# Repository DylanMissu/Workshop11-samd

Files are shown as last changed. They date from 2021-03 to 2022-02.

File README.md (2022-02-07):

# LoRaWAN Logger ZERO+
| Front | Back |
|---|---|
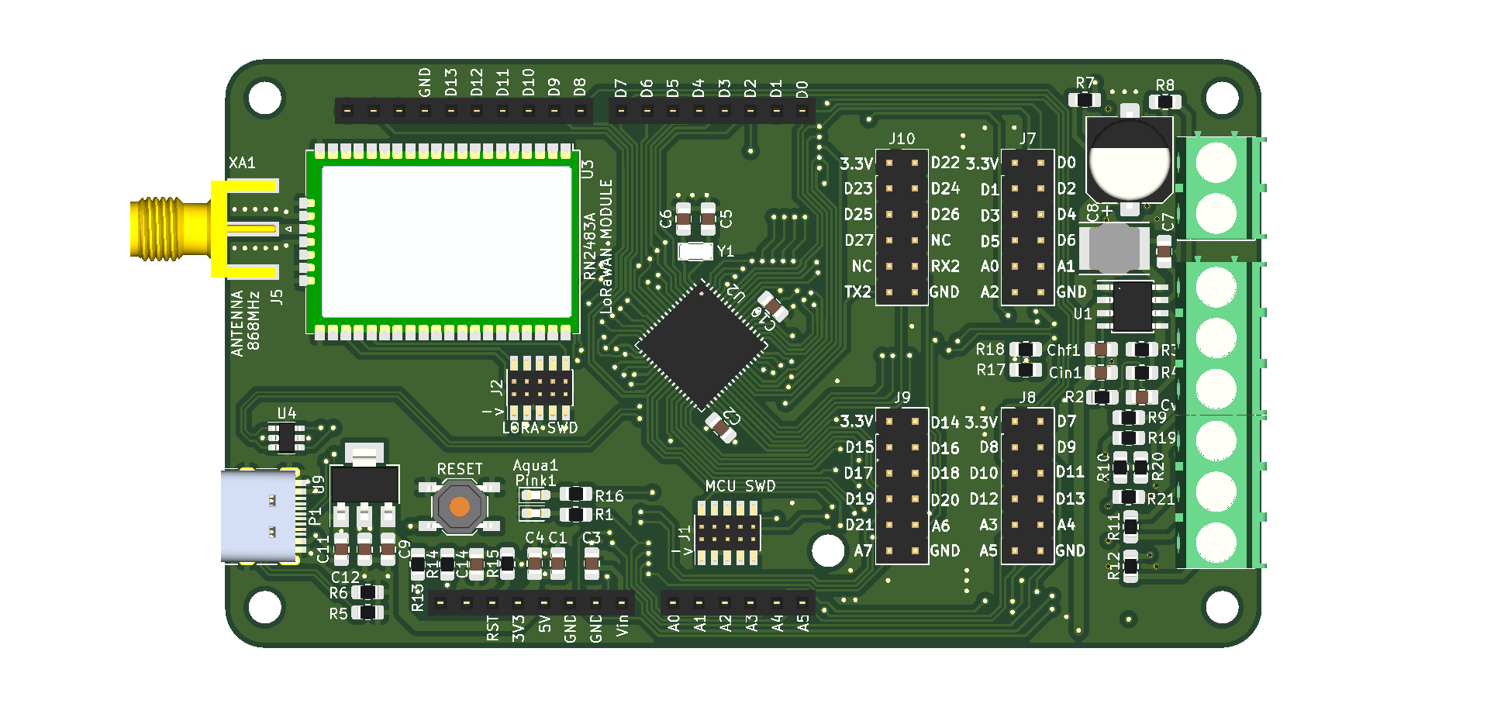
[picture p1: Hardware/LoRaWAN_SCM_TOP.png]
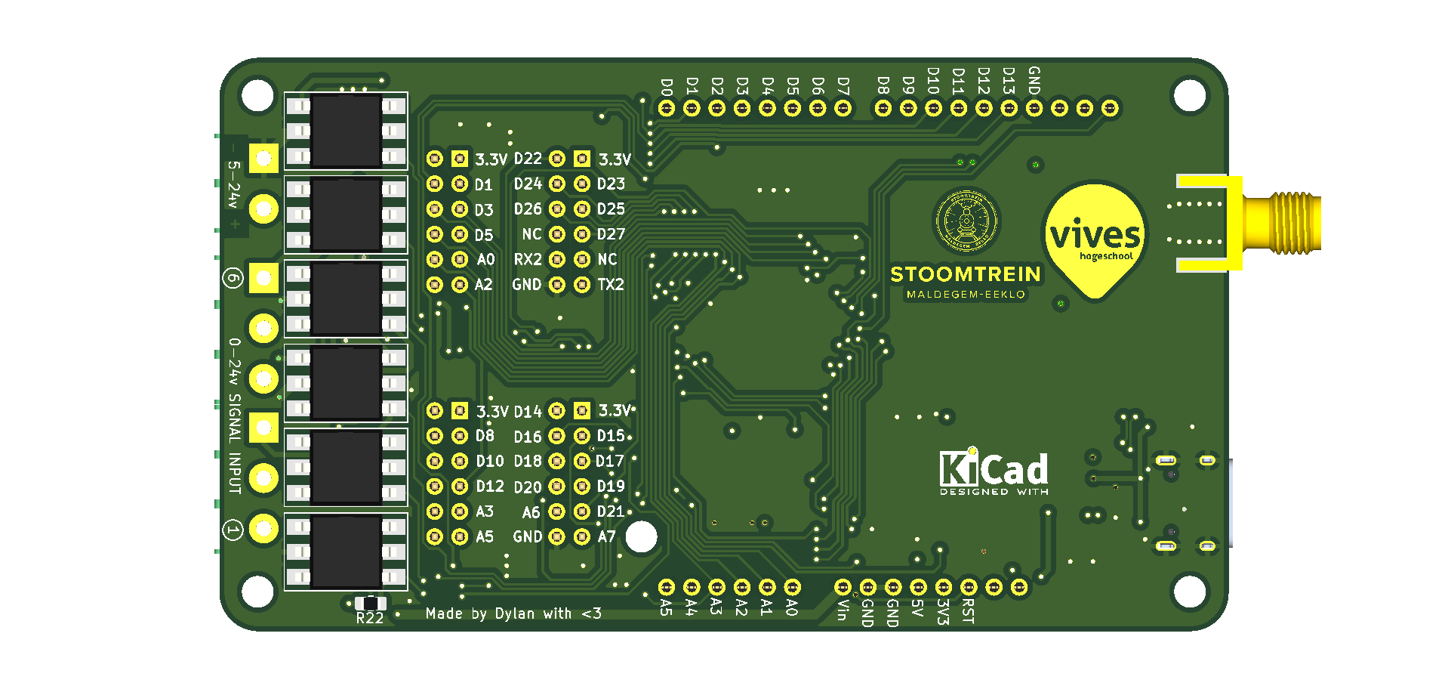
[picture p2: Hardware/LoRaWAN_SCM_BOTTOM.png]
| |  |

## Description
This board was made to help automate steam train management in an NPO. It is used to send status signals to a central server through LoRaWAN so the workers don’t have to go on site and check the states. There will also be an expansion board with relays to switch certain peripherals remotely.
It is equipped with 6 individual 24v tolerant isolated digital inputs. It can also be powered by 24v DC because it uses a buck converter to step the voltage down to 3.3v
Here are some other specifications:
* Microcontroller: ATSAMD21J18
* Flash: 256KB
* SRAM: 64KB
* Frequency: 48MHz
* ADC: 20-Channel 12bit
* DAC: Single-Channel 10bit 
* Pins: 52 GPIO pins

## This repository contains
* installation guide
* usage guide
* PCB and schematic files
* bootloader code and binaries
* ArduinoCore-samd libraries

## Installation
First open the configuration editor in Arduino under "File -> Preferences"
Then next to "Additional Boards Manager URLs" add the following url:
```
https://raw.githubusercontent.com/dylanmsu/Workshop11-samd/master/Workshop11Core-samd/package_workshop11_index.json
```

For a more detailed explanation, refer to [this guide](https://support.arduino.cc/hc/en-us/articles/360016119519-How-to-add-boards-in-the-board-manager).

## Usage
TODO

## Schematic
TODO

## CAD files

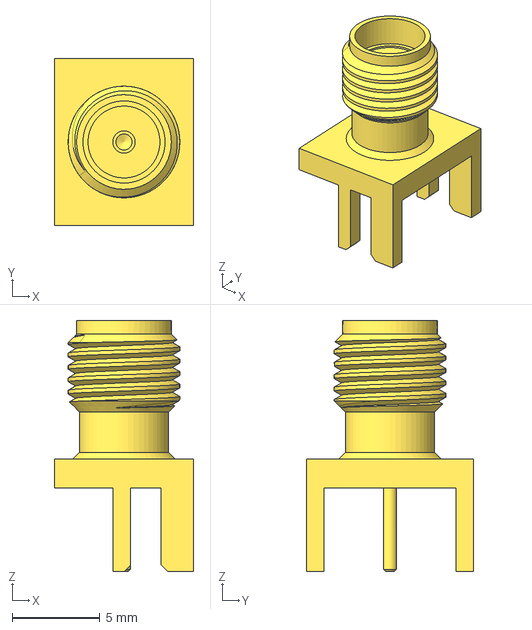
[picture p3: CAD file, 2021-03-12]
Hardware/3d models/142-0701-801--3DModel-STEP-231308.STEP
7.92 x 9.53 x 14.3 mm

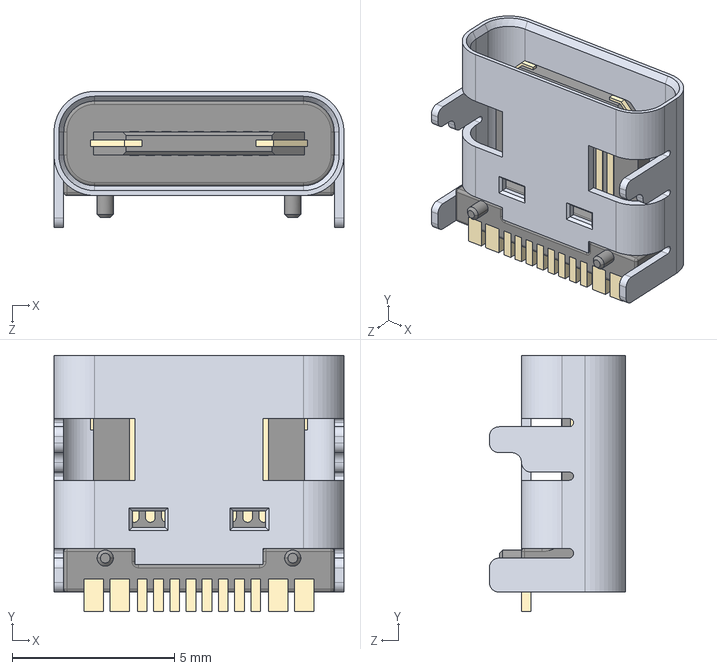
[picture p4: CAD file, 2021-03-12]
Hardware/3d models/USB Type C Port (SMD Type).STEP
8.94 x 7.90 x 4.20 mm

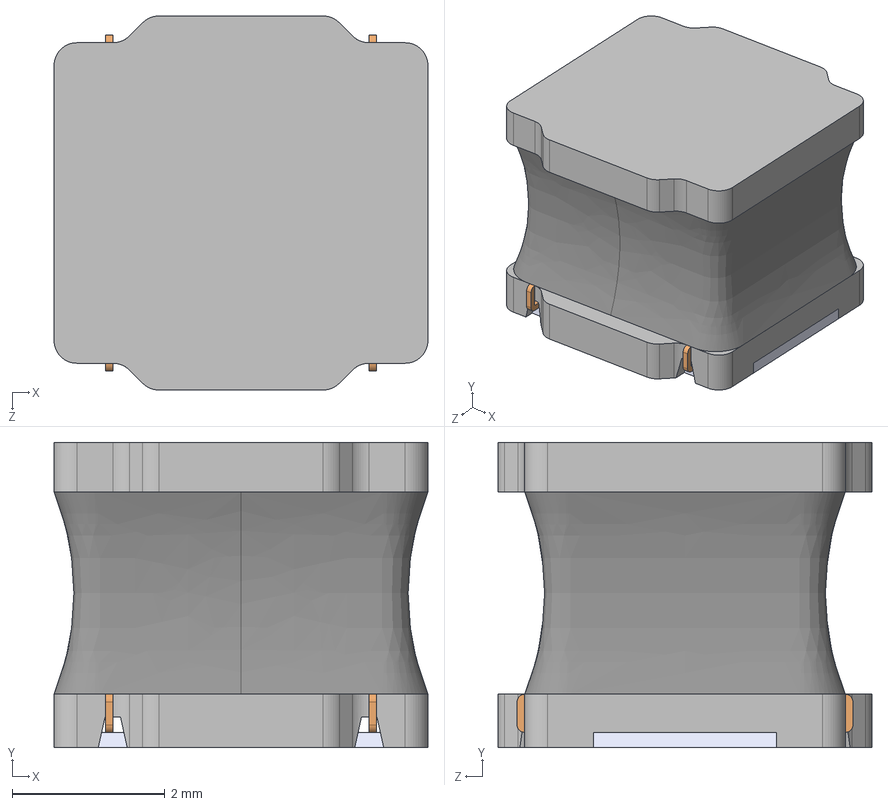
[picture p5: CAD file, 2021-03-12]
Hardware/3d models/LQH5BPN100M38K.STEP
4.90 x 4.00 x 4.90 mm

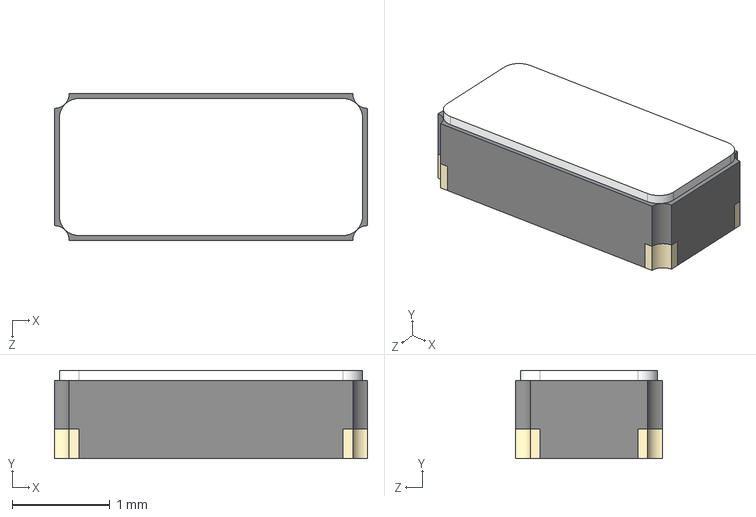
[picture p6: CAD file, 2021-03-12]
Hardware/3d models/ABS07-32.768KHZ-T--3DModel-STEP-56544.STEP
3.20 x 0.9 x 1.50 mm

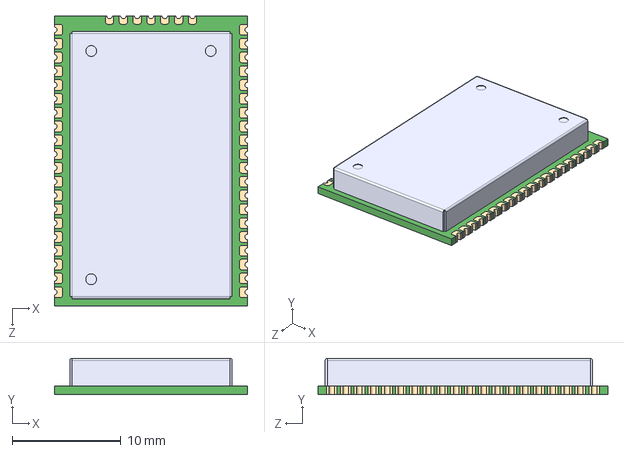
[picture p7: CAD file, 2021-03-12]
Hardware/3d models/RM095--3DModel-STEP-56544.STEP
17.8 x 3.34 x 26.7 mm

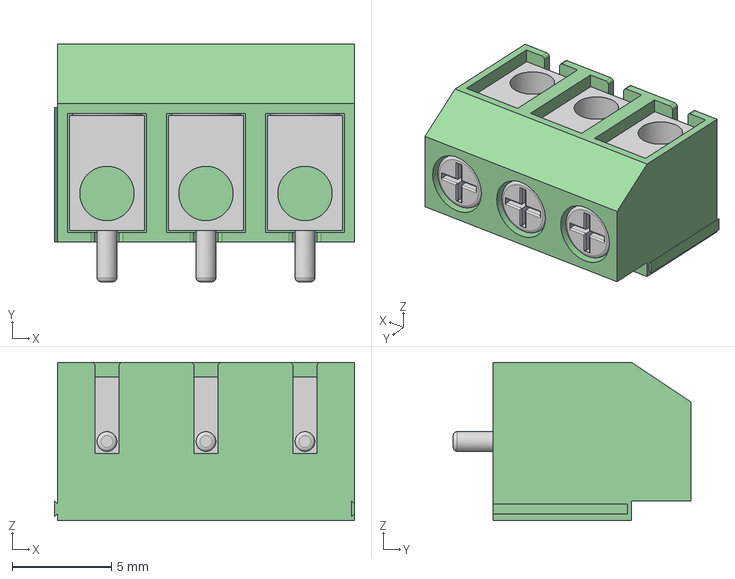
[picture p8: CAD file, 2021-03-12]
Hardware/3d models/Screw Terminal Block 5mm 3-way.step
15.2 x 12.0 x 8.00 mm

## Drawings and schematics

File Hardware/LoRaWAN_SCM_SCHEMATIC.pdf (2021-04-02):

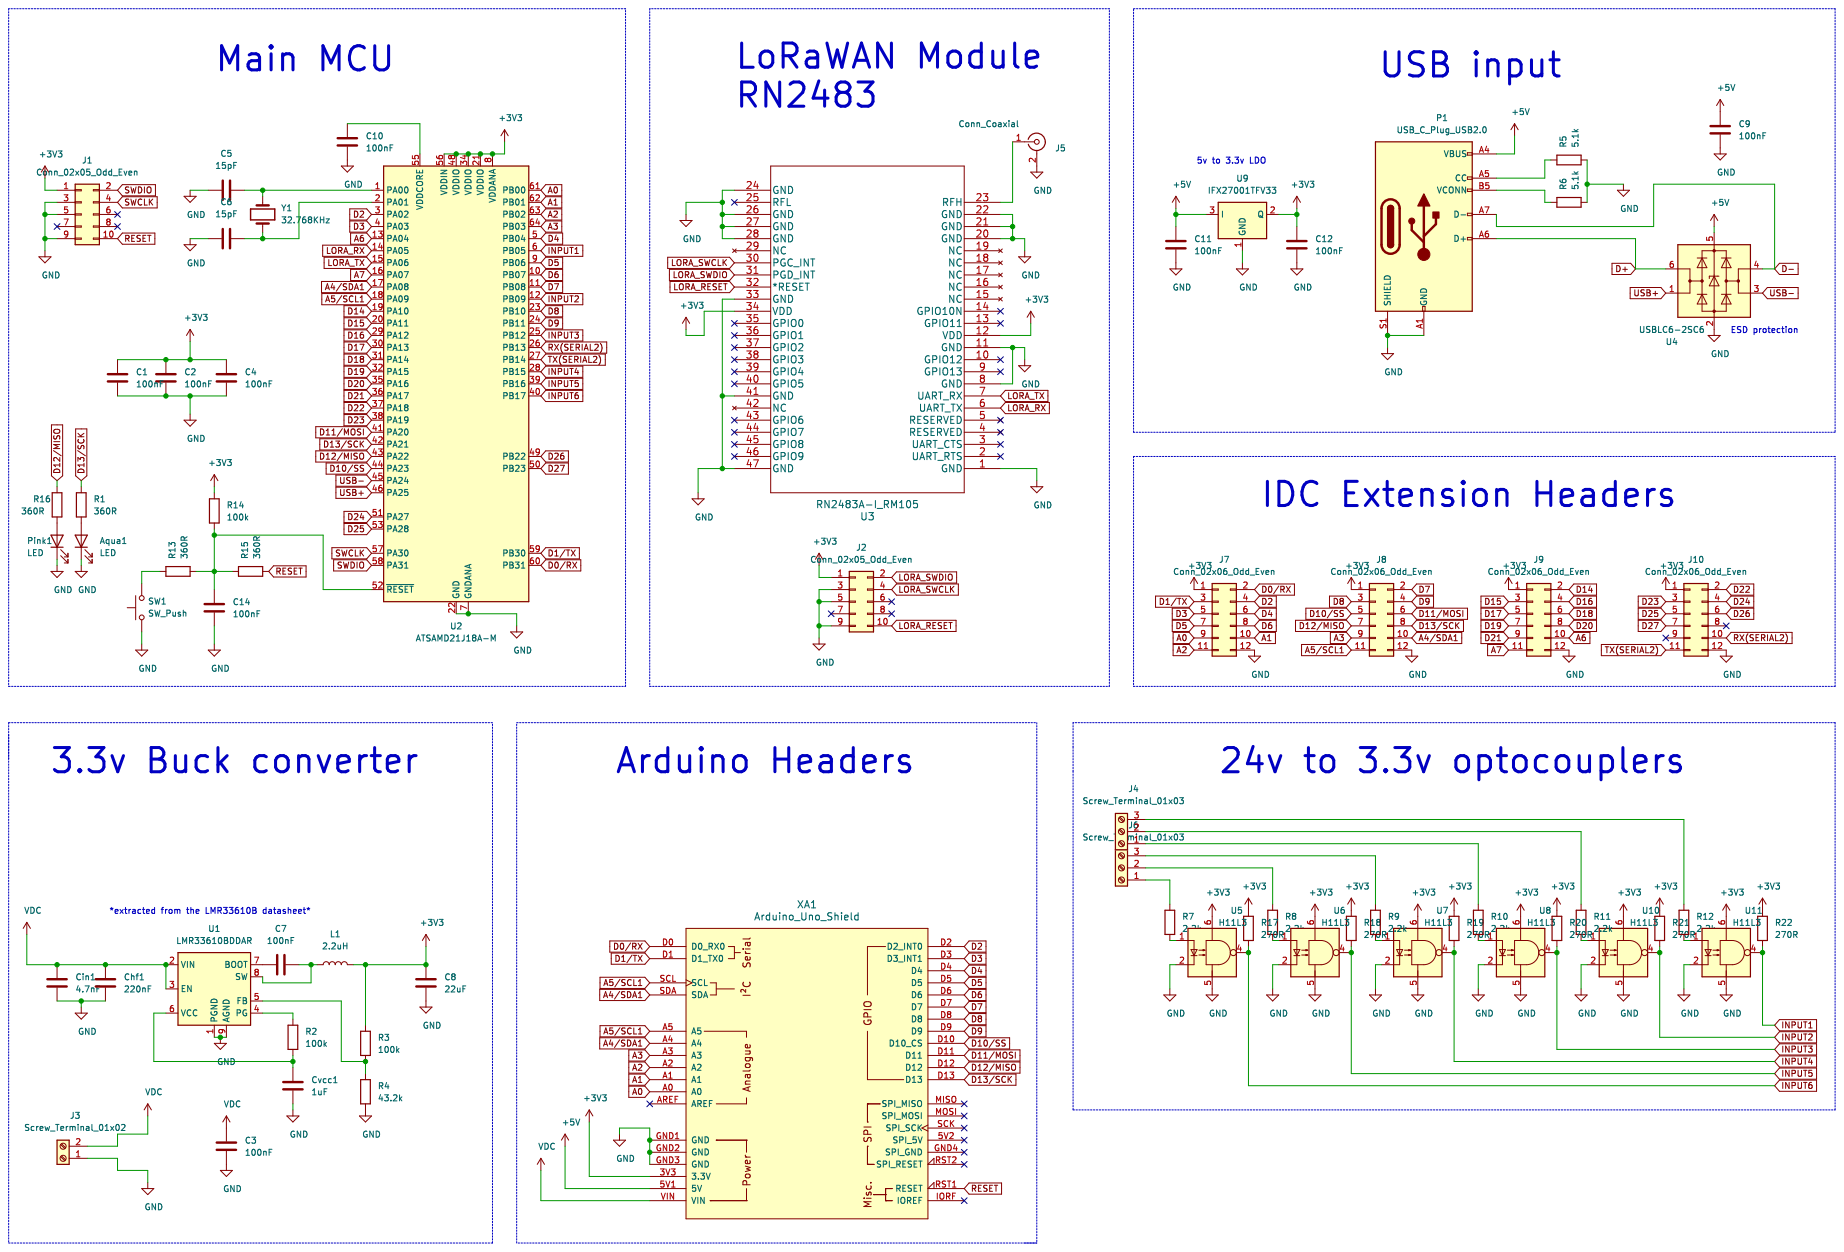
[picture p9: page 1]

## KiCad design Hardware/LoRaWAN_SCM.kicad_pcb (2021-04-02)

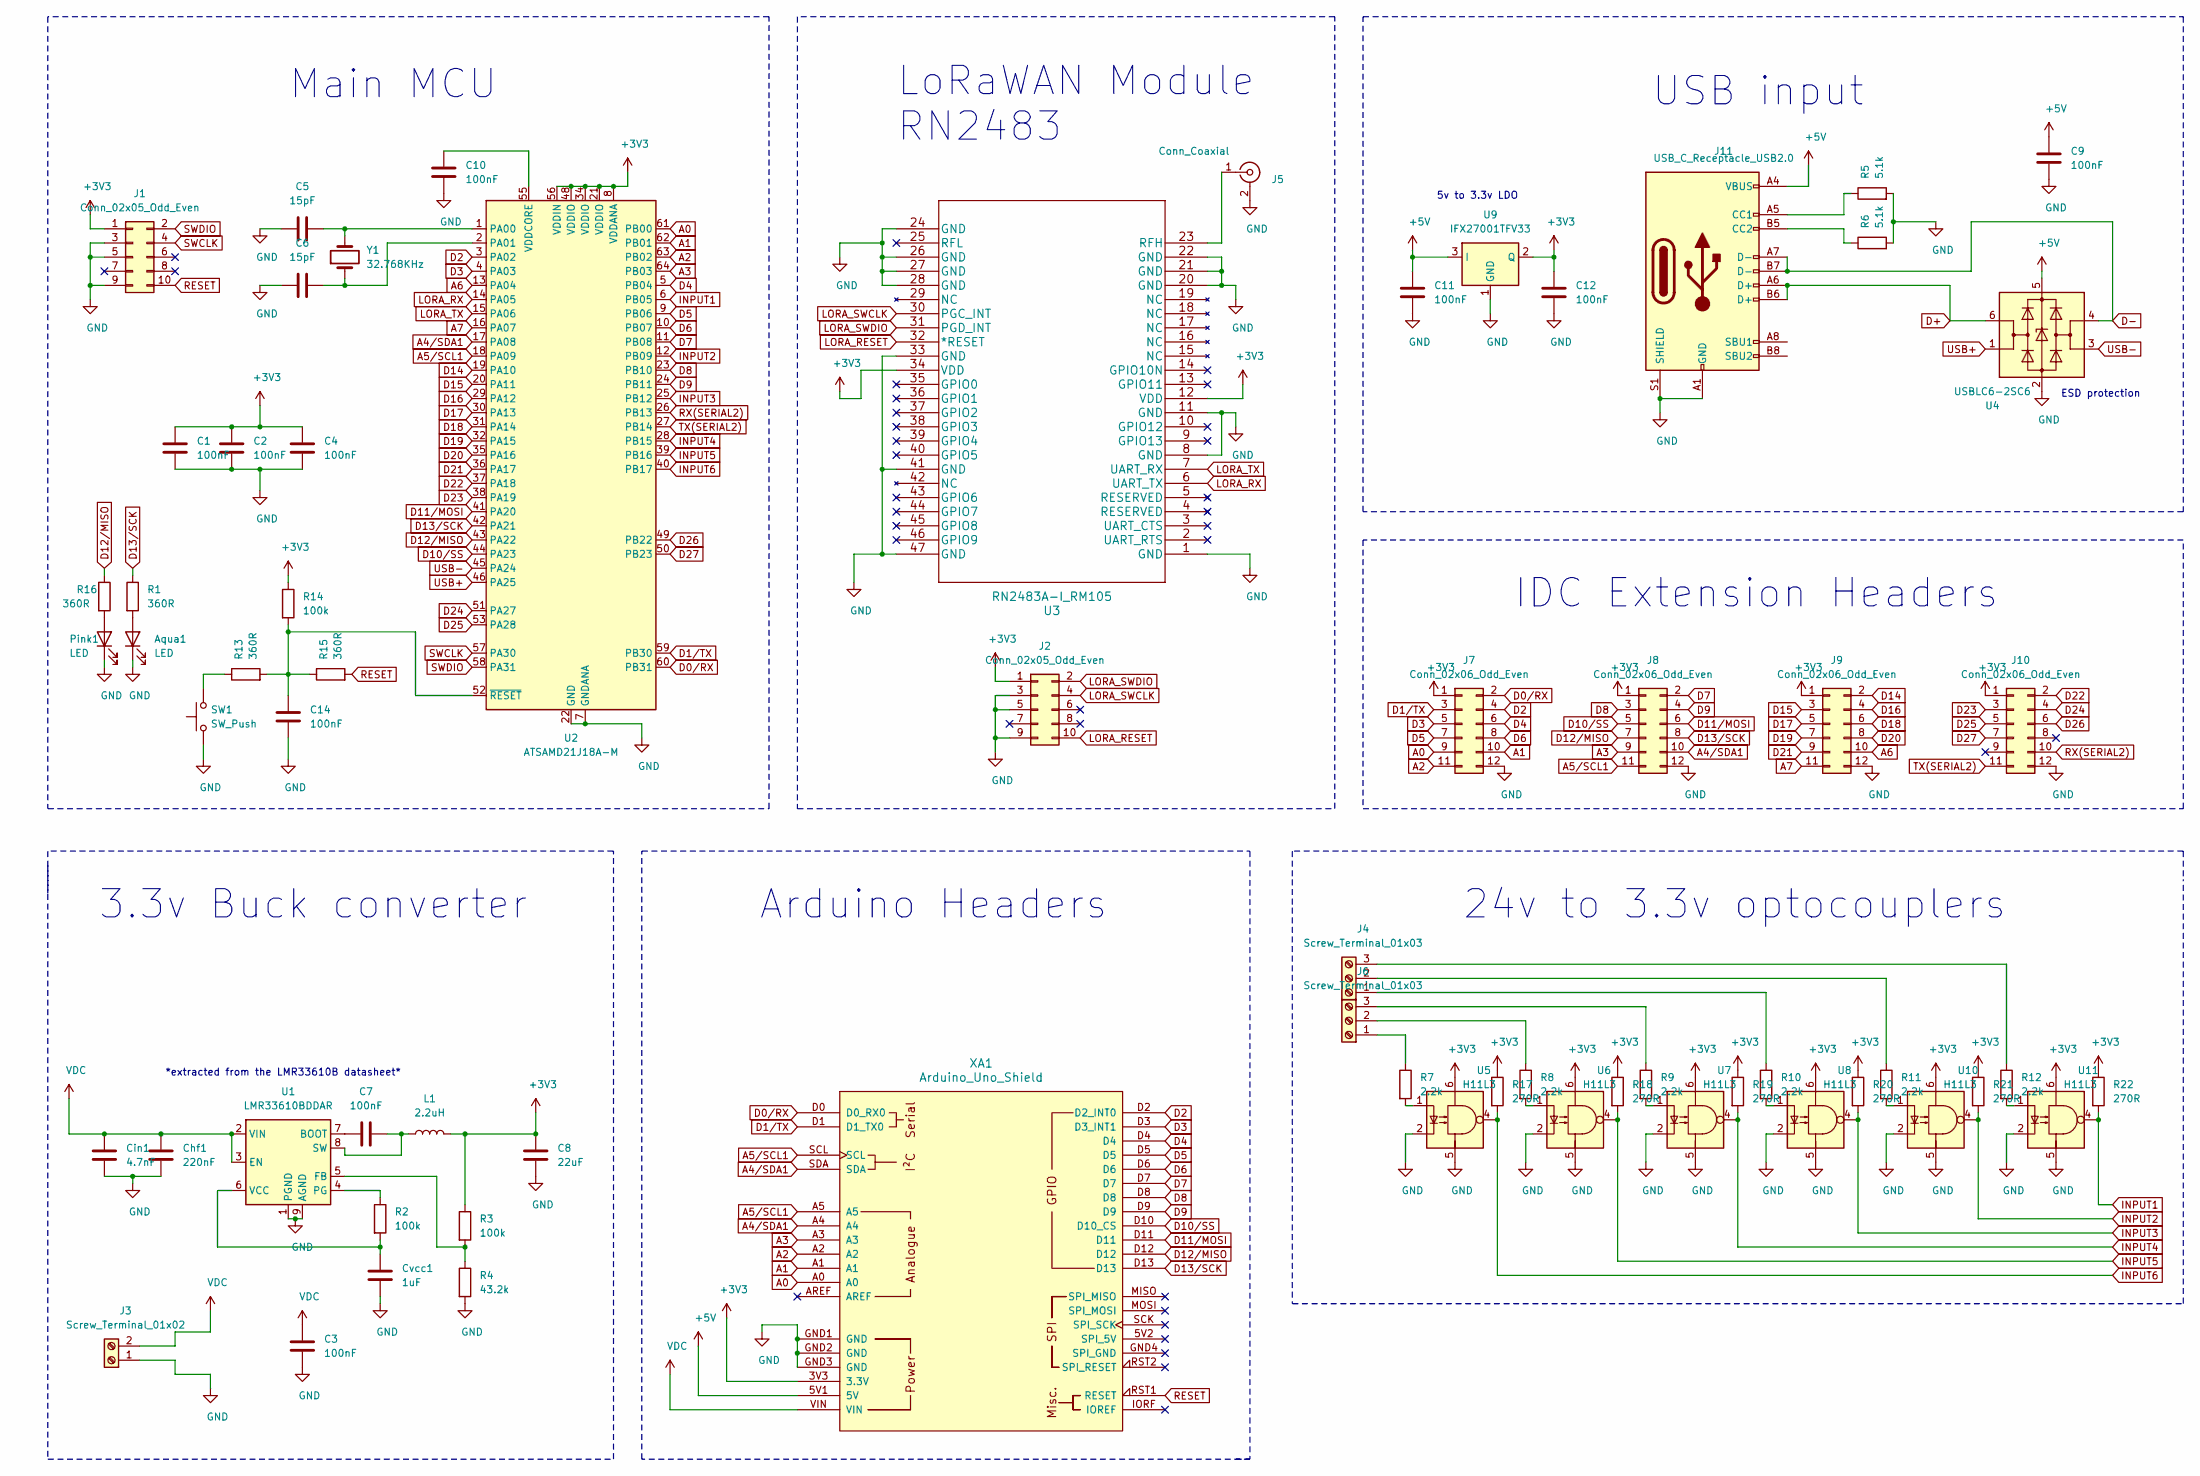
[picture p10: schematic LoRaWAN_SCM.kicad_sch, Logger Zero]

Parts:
Aqua1: LED; LED_0603_1608Metric_Pad1.05x0.95mm_HandSolder
C1, C2, C3, C4, C7, C9, C10, C11, C12, C14: 100nF; C_0805_2012Metric_Pad1.18x1.45mm_HandSolder
C5, C6: 15pF; C_0805_2012Metric_Pad1.18x1.45mm_HandSolder
C8: 22uF; CP_Elec_8x6.9
Chf1: 220nF; C_0805_2012Metric_Pad1.18x1.45mm_HandSolder
Cin1: 4.7nF; C_0805_2012Metric_Pad1.18x1.45mm_HandSolder
Cvcc1: 1uF; C_0805_2012Metric_Pad1.18x1.45mm_HandSolder
J1, J2: Conn_02x05_Odd_Even; PinHeader_2x05_P1.27mm_Vertical_SMD
J3: Screw_Terminal_01x02; TerminalBlock_bornier-2_P5.08mm
J4, J6: Screw_Terminal_01x03; TerminalBlock_bornier-3_P5.08mm
J5: Conn_Coaxial; SMA_Amphenol_132289_EdgeMount
J7, J8, J9, J10: Conn_02x06_Odd_Even; PinHeader_2x06_P2.54mm_Vertical
J11: USB_C_Receptacle_USB2.0
L1: 2.2uH; L_Taiyo-Yuden_NR-50xx_HandSoldering
Pink1: LED; LED_0603_1608Metric_Pad1.05x0.95mm_HandSolder
R1, R13, R15, R16: 360R; R_0805_2012Metric_Pad1.20x1.40mm_HandSolder
R2, R3, R14: 100k; R_0805_2012Metric_Pad1.20x1.40mm_HandSolder
R4: 43.2k; R_0805_2012Metric_Pad1.20x1.40mm_HandSolder
R5, R6: 5.1k; R_0805_2012Metric_Pad1.20x1.40mm_HandSolder
R7, R8, R9, R10, R11, R12: 2.2k; R_0805_2012Metric_Pad1.20x1.40mm_HandSolder
R17, R18, R19, R20, R21, R22: 270R; R_0805_2012Metric_Pad1.20x1.40mm_HandSolder
SW1: SW_Push; SW_SPST_TL3342
U1: LMR33610BDDAR; Texas_HSOP-8-1EP_3.9x4.9mm_P1.27mm_ThermalVias
U2: ATSAMD21J18A-M; QFN-64-1EP_9x9mm_P0.5mm_EP4.7x4.7mm
U3: RN2483A-I_RM105; RN2483
U4: USBLC6-2SC6; SOT-23-6
U5, U6, U7, U8, U10, U11: H11L3; DIP-6_W8.89mm_SMDSocket_LongPads
U9: IFX27001TFV33; SOT-223-3_TabPin2
XA1: Arduino_Uno_Shield
Y1: 32.768KHz; Crystal_SMD_3215-2Pin_3.2x1.5mm

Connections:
+3V3: C1.1, C2.1, C4.1, C8.1, C12.1, J1.1, J2.1, J7.1, J8.1, J9.1, J10.1, L1.2, R3.1, R14.1, R17.1, R18.1, R19.1, R20.1, R21.1, R22.1, U2.8 (VDDANA), U2.21 (VDDIO), U2.34 (VDDIO), U2.48 (VDDIO), U2.56 (VDDIN), U3.12 (VDD), U3.34 (VDD), U5.6, U6.6, U7.6, U8.6, U9.2 (Q), U10.6, U11.6, XA1.3V3 (3.3V)
+5V: C9.1, C11.1, J11.A4 (VBUS), J11.A9 (VBUS), J11.B4 (VBUS), J11.B9 (VBUS), U4.5 (VBUS), U9.3 (I), XA1.5V1 (5V); also elsewhere on the board
A0: J7.9, U2.61 (PB00), XA1.A0
A1: J7.10, U2.62 (PB01), XA1.A1
A2: J7.11, U2.63 (PB02), XA1.A2
A3: J8.9, U2.64 (PB03), XA1.A3
A4/SDA1: J8.10, U2.17 (PA08), XA1.A4, XA1.SDA
A5/SCL1: J8.11, U2.18 (PA09), XA1.A5, XA1.SCL
A6: J9.10, U2.13 (PA04)
A7: J9.11, U2.16 (PA07)
D0/RX: J7.2, U2.60 (PB31), XA1.D0 (D0_RX0)
D1/TX: J7.3, U2.59 (PB30), XA1.D1 (D1_TX0)
D2: J7.4, U2.3 (PA02), XA1.D2 (D2_INT0)
D3: J7.5, U2.4 (PA03), XA1.D3 (D3_INT1)
D4: J7.6, U2.5 (PB04), XA1.D4
D5: J7.7, U2.9 (PB06), XA1.D5
D6: J7.8, U2.10 (PB07), XA1.D6
D7: J8.2, U2.11 (PB08), XA1.D7
D8: J8.3, U2.23 (PB10), XA1.D8
D9: J8.4, U2.24 (PB11), XA1.D9
D10/SS: J8.5, U2.44 (PA23), XA1.D10 (D10_CS)
D11/MOSI: J8.6, U2.41 (PA20), XA1.D11
D12/MISO: J8.7, R16.1, U2.43 (PA22), XA1.D12
D13/SCK: J8.8, R1.1, U2.42 (PA21), XA1.D13
D14: J9.2, U2.19 (PA10)
D15: J9.3, U2.20 (PA11)
D16: J9.4, U2.29 (PA12)
D17: J9.5, U2.30 (PA13)
D18: J9.6, U2.31 (PA14)
D19: J9.7, U2.32 (PA15)
D20: J9.8, U2.35 (PA16)
D21: J9.9, U2.36 (PA17)
D22: J10.2, U2.37 (PA18)
D23: J10.3, U2.38 (PA19)
D24: J10.4, U2.51 (PA27)
D25: J10.5, U2.53 (PA28)
D26: J10.6, U2.49 (PB22)
D27: J10.7, U2.50 (PB23)
D+: J11.A6 (D+), J11.B6 (D+), U4.6 (I/O1); also elsewhere on the board
D-: J11.A7 (D-), J11.B7 (D-), U4.4 (I/O2); also elsewhere on the board
GND: Aqua1.1 (K), C1.2, C2.2, C3.2, C4.2, C5.1, C6.1, C8.2, C9.2, C10.2, C11.2, C12.2, C14.2, Chf1.2, Cin1.2, Cvcc1.2, J1.3, J1.5, J1.9, J2.3, J2.5, J2.9, J3.1, J5.2 (Ext), J7.12, J8.12, J9.12, J10.12, J11.A1 (GND), J11.A12 (GND), J11.B1 (GND), J11.B12 (GND), J11.S1 (SHIELD), Pink1.1 (K), R4.2, R5.2, R6.2, SW1.1, U1.1 (PGND), U1.9 (AGND), U2.7 (GNDANA), U2.22 (GND), U2.33 (GND), U2.47 (GND), U2.54 (GND), U3.1 (GND), U3.8 (GND), U3.11 (GND), U3.20 (GND), U3.21 (GND), U3.22 (GND), U3.24 (GND), U3.26 (GND), U3.27 (GND), U3.28 (GND), U3.33 (GND), U3.41 (GND), U3.47 (GND), U4.2 (GND), U5.2, U5.5, U6.2, U6.5, U7.2, U7.5, U8.2, U8.5, U9.1 (GND), U10.2, U10.5, U11.2, U11.5, XA1.GND1 (GND), XA1.GND2 (GND), XA1.GND3 (GND); also elsewhere on the board
INPUT1: R22.2, U2.6 (PB05), U11.4
INPUT2: R21.2, U2.12 (PB09), U10.4
INPUT3: R20.2, U2.25 (PB12), U8.4
INPUT4: R19.2, U2.28 (PB15), U7.4
INPUT5: R18.2, U2.39 (PB16), U6.4
INPUT6: R17.2, U2.40 (PB17), U5.4
LORA_RESET: J2.10, U3.32 (*RESET)
LORA_RX: U2.14 (PA05), U3.6 (UART_TX)
LORA_SWCLK: J2.4, U3.30 (PGC_INT)
LORA_SWDIO: J2.2, U3.31 (PGD_INT)
LORA_TX: U2.15 (PA06), U3.7 (UART_RX)
unnamed: Aqua1.2 (A), R1.2
unnamed: C5.2, U2.1 (PA00), Y1.2
unnamed: C6.2, U2.2 (PA01), Y1.1
unnamed: C7.1, L1.1, U1.8 (SW)
unnamed: C7.2, U1.7 (BOOT)
unnamed: C10.1, U2.55 (VDDCORE)
unnamed: C14.1, R13.2, R14.2, R15.1, U2.52 (~RESET)
unnamed: Cvcc1.1, R2.2, U1.6 (VCC)
unnamed: J4.1, R10.1
unnamed: J4.2, R11.1
unnamed: J4.3, R12.1
unnamed: J5.1 (In), U3.23 (RFH)
unnamed: J6.1, R7.1
unnamed: J6.2, R8.1
unnamed: J6.3, R9.1
unnamed: Pink1.2 (A), R16.2
unnamed: R2.1, U1.4 (PG)
unnamed: R3.2, R4.1, U1.5 (FB)
unnamed: J11.A5 (CC1), R5.1
unnamed: J11.B5 (CC2), R6.1
unnamed: R7.2, U5.1
unnamed: R8.2, U6.1
unnamed: R9.2, U7.1
unnamed: R10.2, U8.1
unnamed: R11.2, U10.1
unnamed: R12.2, U11.1
unnamed: R13.1, SW1.2
RESET: J1.10, R15.2, XA1.RST1 (RESET)
RX(SERIAL2): J10.10, U2.26 (PB13)
SWCLK: J1.4, U2.57 (PA30)
SWDIO: J1.2, U2.58 (PA31)
TX(SERIAL2): J10.11, U2.27 (PB14)
USB+: U2.46 (PA25), U4.1 (I/O1)
USB-: U2.45 (PA24), U4.3 (I/O2)
VDC: C3.1, Chf1.1, Cin1.1, J3.2, U1.2 (VIN), U1.3 (EN), XA1.VIN

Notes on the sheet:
Main MCU
*extracted from the LMR33610B datasheet*
3.3v Buck converter
LoRaWAN Module RN2483
Arduino Headers
24v to 3.3v optocouplers
5v to 3.3v LDO
USB input
IDC Extension Headers
ESD protection

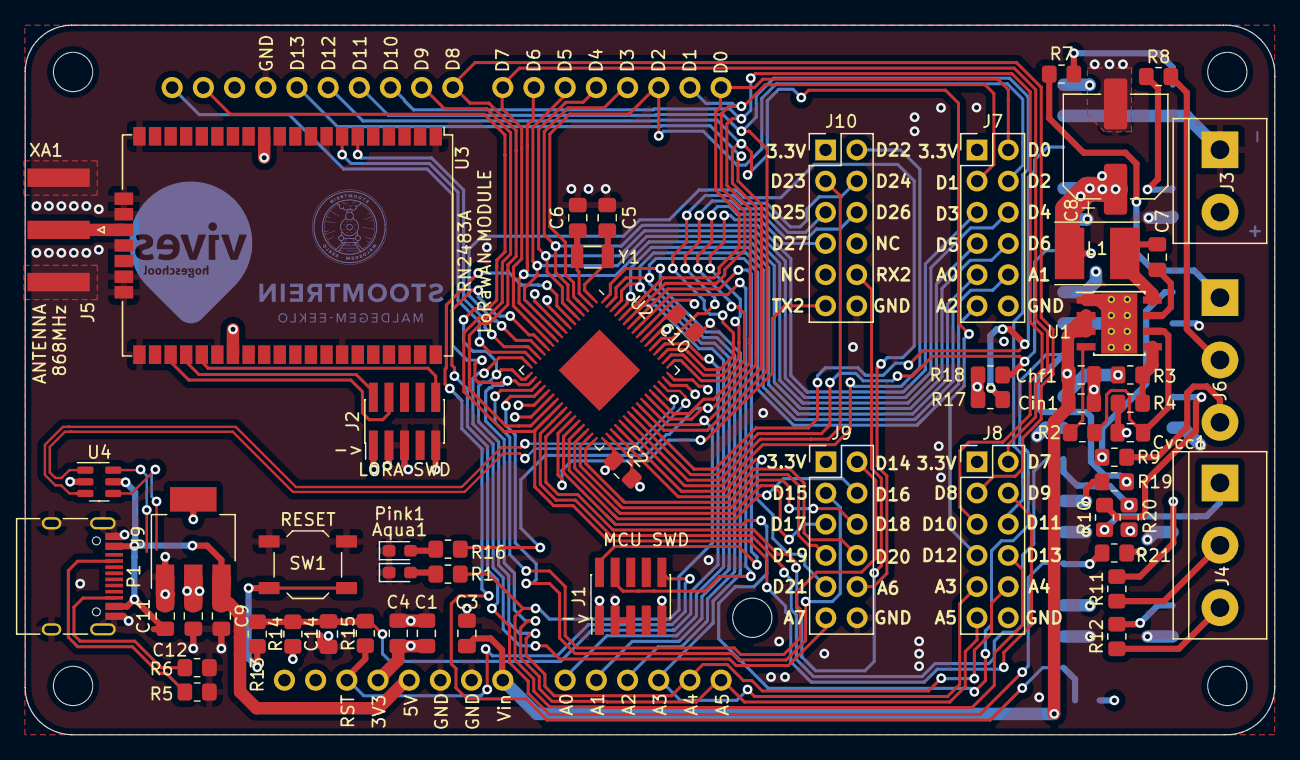
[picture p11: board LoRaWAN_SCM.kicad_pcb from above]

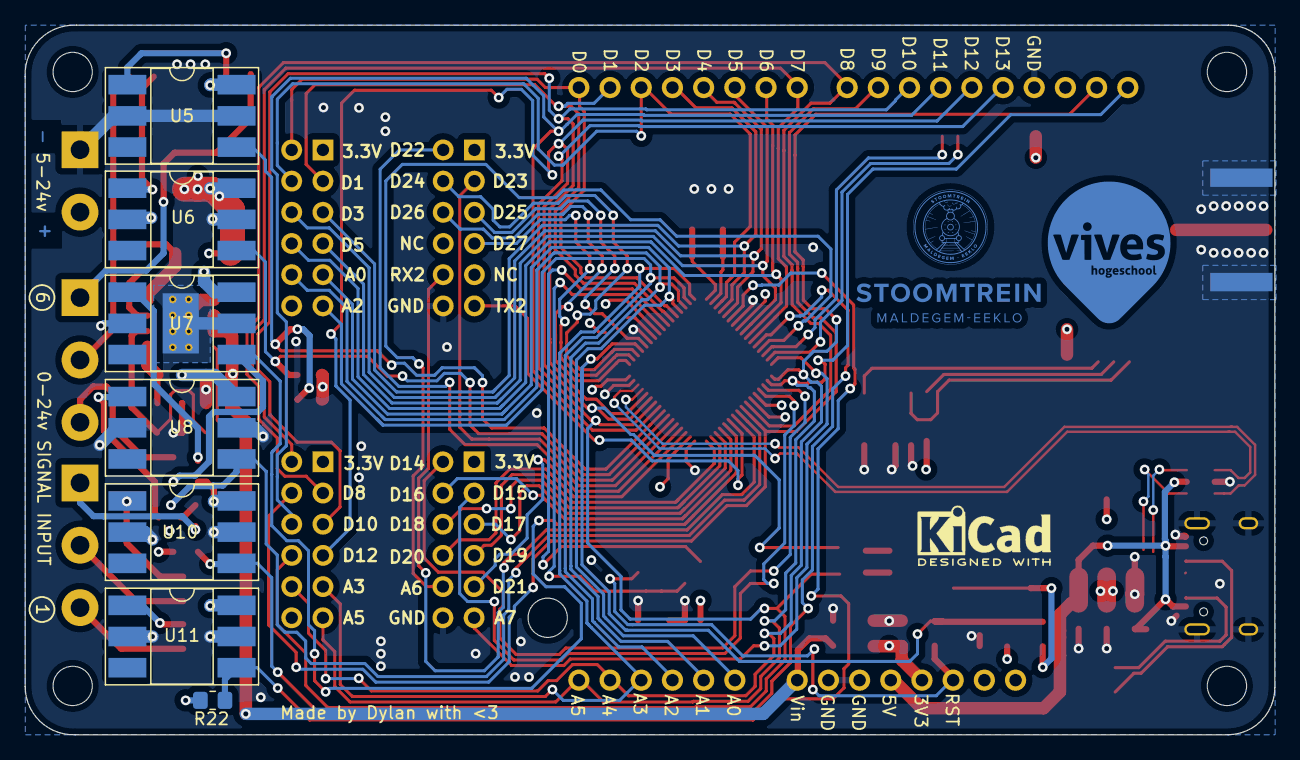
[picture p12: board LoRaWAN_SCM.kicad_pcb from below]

Board: 4 copper layers, 101.8 x 57.8 mm, 66 parts (7 on the bottom side), 85 nets.

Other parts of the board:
P1: USB_C_Plug_USB2.0; USB_C_Receptacle_HRO_TYPE-C-31-M-12

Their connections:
+5V: P1.A4 (VBUS), P1.A9 (VBUS), P1.B4 (VBUS), P1.B9 (VBUS); also elsewhere on the board
D+: P1.A6 (D+); also elsewhere on the board
D-: P1.A7 (D-); also elsewhere on the board
GND: P1.A1 (GND), P1.A12 (GND), P1.B1 (GND), P1.B12 (GND), P1.S1 (SHIELD); also elsewhere on the board

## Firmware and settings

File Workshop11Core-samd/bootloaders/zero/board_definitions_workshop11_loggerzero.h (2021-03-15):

/*
  Copyright (c) 2016 SODAQ.  All right reserved.

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
  You should have received a copy of the GNU Lesser General Public
  License along with this library; if not, write to the Free Software
  Foundation, Inc., 51 Franklin St, Fifth Floor, Boston, MA  02110-1301  USA
*/

#ifndef _BOARD_DEFINITIONS_H_
#define _BOARD_DEFINITIONS_H_

/*
 * USB device definitions
 */
#define STRING_PRODUCT "Logger Zero"
#define USB_VID_HIGH   0x23
#define USB_VID_LOW    0x41
#define USB_PID_HIGH   0xff//0x02   //change product id to not confuse arduino
#define USB_PID_LOW    0x4D

/*
 * If BOOT_DOUBLE_TAP_ADDRESS is defined the bootloader is started by
 * quickly tapping two times on the reset button.
 * BOOT_DOUBLE_TAP_ADDRESS must point to a free SRAM cell that must not
 * be touched from the loaded application.
 */
#define BOOT_DOUBLE_TAP_ADDRESS           (0x20007FFCul)
#define BOOT_DOUBLE_TAP_DATA              (*((volatile uint32_t *) BOOT_DOUBLE_TAP_ADDRESS))

/*
 * If BOOT_LOAD_PIN is defined the bootloader is started if the selected
 * pin is tied LOW.
 */
//#define BOOT_LOAD_PIN                     PIN_PA21 // Pin 7
//#define BOOT_LOAD_PIN                     PIN_PA15 // Pin 5

#define BOOT_USART_MODULE                 SERCOM0
#define BOOT_USART_BUS_CLOCK_INDEX        PM_APBCMASK_SERCOM0
#define BOOT_USART_PER_CLOCK_INDEX        GCLK_CLKCTRL_ID_SERCOM0_CORE_Val
#define BOOT_USART_PAD_SETTINGS           UART_RX_PAD1_TX_PAD0
#define BOOT_USART_PAD3                   PINMUX_UNUSED
#define BOOT_USART_PAD2                   PINMUX_UNUSED
#define BOOT_USART_PAD1                   PINMUX_PB31D_SERCOM5_PAD1
#define BOOT_USART_PAD0                   PINMUX_PB30D_SERCOM5_PAD0


/* Master clock frequency */
#define CPU_FREQUENCY                     (48000000ul)
#define VARIANT_MCK                       CPU_FREQUENCY

/* Frequency of the board main oscillator */
#define VARIANT_MAINOSC                   (32768ul)

/* Calibration values for DFLL48 pll */
#define NVM_SW_CALIB_DFLL48M_COARSE_VAL   (58)
#define NVM_SW_CALIB_DFLL48M_FINE_VAL     (64)

/*
 * LEDs definitions
 */
#define BOARD_LED_PORT                    (0)
#define BOARD_LED_PIN                     (22)

//#define BOARD_LEDRX_PORT                  (0)
//#define BOARD_LEDRX_PIN                   (21)

//#define BOARD_LEDTX_PORT                  (0)
//#define BOARD_LEDTX_PIN                   (12)

#endif // _BOARD_DEFINITIONS_H_

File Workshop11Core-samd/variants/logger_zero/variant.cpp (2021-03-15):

/*
  Copyright (c) 2014-2015 Arduino LLC.  All right reserved.

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
  You should have received a copy of the GNU Lesser General Public
  License along with this library; if not, write to the Free Software
  Foundation, Inc., 51 Franklin St, Fifth Floor, Boston, MA  02110-1301  USA
*/
/*
 * +------------+------------------+--------+-----------------+--------------------------------------------------------------------------------------------------------
 * + Pin number +  Autonomo pin    |  PIN   | Label/Name      | Comments (* is for default peripheral in use)
 * +------------+------------------+--------+-----------------+--------------------------------------------------------------------------------------------------------
 * |            | Digital Low      |        |                 |
 * +------------+------------------+--------+-----------------+--------------------------------------------------------------------------------------------------------
 */


#include "variant.h"

/*
 * Pins descriptions for Workshop11 Logger Zero
 *
 *  0..15 digital
 * 16..31 analog, A0..A15
 */
const PinDescription g_APinDescription[]=
{ 
  /*
  | PORT | PIN | PIN_TYPE    | PIN_ATTRIBUTES                                    | ADC_CHANNEL   | PWM_CHANNEL | TIMER_CHANNEL | EXT. INTERRUPT |
  */

  //0
  { PORTB, 31, PIO_SERCOM_ALT,  PIN_ATTR_DIGITAL,                                      No_ADC_Channel, NOT_ON_PWM, NOT_ON_TIMER, EXTERNAL_INT_15  }, // RX, SERCOM5/PAD[1], D0
  
  //1
  { PORTB, 30, PIO_SERCOM_ALT,  PIN_ATTR_DIGITAL,                                      No_ADC_Channel, NOT_ON_PWM, NOT_ON_TIMER, EXTERNAL_INT_14  }, // TX, SERCOM5/PAD[0], D1

  //2
  { PORTA, 2,  PIO_ANALOG,      PIN_ATTR_DIGITAL,                                      DAC_Channel0,   NOT_ON_PWM, NOT_ON_TIMER, EXTERNAL_INT_2   }, //  D2
  
  //3
  { PORTA, 3,  PIO_OUTPUT,      PIN_ATTR_DIGITAL,                                      No_ADC_Channel, NOT_ON_PWM, NOT_ON_TIMER, EXTERNAL_INT_3   }, //  D3
  
  //4
  { PORTB, 4,  PIO_OUTPUT,      PIN_ATTR_DIGITAL,                                      No_ADC_Channel, NOT_ON_PWM, NOT_ON_TIMER, EXTERNAL_INT_4   }, //  D4
  
  //5
  { PORTB, 6,  PIO_OUTPUT,      PIN_ATTR_DIGITAL,                                      No_ADC_Channel, NOT_ON_PWM, NOT_ON_TIMER, EXTERNAL_INT_6   }, //  D5
  
  //6
  { PORTB, 7,  PIO_OUTPUT,      PIN_ATTR_DIGITAL,                                      No_ADC_Channel, NOT_ON_PWM, NOT_ON_TIMER, EXTERNAL_INT_7   }, //  D6
  
  //7
  { PORTB, 8,  PIO_OUTPUT,      PIN_ATTR_DIGITAL,                                      No_ADC_Channel, NOT_ON_PWM, NOT_ON_TIMER, EXTERNAL_INT_8   }, //  D7
  
  //8
  { PORTB, 10, PIO_TIMER,       (PIN_ATTR_DIGITAL | PIN_ATTR_PWM | PIN_ATTR_TIMER),    No_ADC_Channel, PWM5_CH0,   TC5_CH0,      EXTERNAL_INT_10  }, // TC5[0], D8
  
  //9
  { PORTB, 11, PIO_OUTPUT,      PIN_ATTR_DIGITAL,                                      No_ADC_Channel, NOT_ON_PWM, NOT_ON_TIMER, EXTERNAL_INT_11  }, //  D9
  
  //10
  { PORTA, 23, PIO_TIMER,      (PIN_ATTR_DIGITAL | PIN_ATTR_PWM | PIN_ATTR_TIMER),     No_ADC_Channel, PWM4_CH1,   TC4_CH1,      EXTERNAL_INT_7   }, // TC4[1], D10
  
  //11
  { PORTA, 20, PIO_TIMER,      (PIN_ATTR_DIGITAL | PIN_ATTR_PWM | PIN_ATTR_TIMER),     No_ADC_Channel, PWM7_CH0,   TC7_CH0,      EXTERNAL_INT_4   }, // TC7[0], D11
  
  //12
  { PORTA, 22, PIO_TIMER,      (PIN_ATTR_DIGITAL | PIN_ATTR_PWM | PIN_ATTR_TIMER),     No_ADC_Channel, PWM4_CH0,   TC4_CH0,      EXTERNAL_INT_6   }, // TC4[0], D12
  
  //13
  { PORTA, 21, PIO_TIMER,      (PIN_ATTR_DIGITAL | PIN_ATTR_PWM | PIN_ATTR_TIMER),     No_ADC_Channel, PWM1_CH0,   TC7_CH1,      EXTERNAL_INT_5   }, // TC7[1], D13 LED_BUILTIN
  
  //14
  { PORTA, 10, PIO_TIMER,      (PIN_ATTR_DIGITAL | PIN_ATTR_PWM | PIN_ATTR_TIMER),     No_ADC_Channel, PWM7_CH1,   TCC1_CH0,     EXTERNAL_INT_10  }, // TCC1[0], D14
  
  //15
  { PORTA, 11, PIO_TIMER,      (PIN_ATTR_DIGITAL | PIN_ATTR_PWM | PIN_ATTR_TIMER),     No_ADC_Channel, PWM1_CH1,   TCC1_CH1,     EXTERNAL_INT_11  }, // TCC1[1], D15

  //16
  { PORTA, 12, PIO_TIMER,      (PIN_ATTR_DIGITAL | PIN_ATTR_PWM | PIN_ATTR_TIMER),     No_ADC_Channel, PWM2_CH0,   TCC2_CH0,     EXTERNAL_INT_NONE}, // TCC2[0], LED_RED,  D16
  
  //17
  { PORTA, 13, PIO_TIMER,      (PIN_ATTR_DIGITAL | PIN_ATTR_PWM | PIN_ATTR_TIMER),     No_ADC_Channel, PWM5_CH1,   TC5_CH1,      EXTERNAL_INT_NONE}, // TC5[1], LED_GREEN, D17
  
  //18
  { PORTA, 14, PIO_TIMER,      (PIN_ATTR_DIGITAL | PIN_ATTR_PWM | PIN_ATTR_TIMER),     No_ADC_Channel, PWM2_CH1,   TCC2_CH1,     EXTERNAL_INT_NONE},// TCC2[1], LED_BLUE,  D18
  
  //19
  { PORTA, 15, PIO_OUTPUT,      PIN_ATTR_DIGITAL,                                      No_ADC_Channel, NOT_ON_PWM, NOT_ON_TIMER, EXTERNAL_INT_15  },// BLUETOOTH_WAKE,     D19
  
  //20
  { PORTA, 16, PIO_OUTPUT,      PIN_ATTR_DIGITAL,                                      No_ADC_Channel, NOT_ON_PWM, NOT_ON_TIMER, EXTERNAL_INT_NONE},
  
  //21
  { PORTA, 17, PIO_OUTPUT,      PIN_ATTR_DIGITAL,                                      No_ADC_Channel, NOT_ON_PWM, NOT_ON_TIMER, EXTERNAL_INT_NONE},
  
  //22
  { PORTA, 18, PIO_OUTPUT,      PIN_ATTR_DIGITAL,                                      No_ADC_Channel, NOT_ON_PWM, NOT_ON_TIMER, EXTERNAL_INT_NONE},
  
  //23
  { PORTA, 19, PIO_OUTPUT,      PIN_ATTR_DIGITAL,                                      No_ADC_Channel, NOT_ON_PWM, NOT_ON_TIMER, EXTERNAL_INT_NONE},

  //24
  { PORTB,  5, PIO_OUTPUT,      PIN_ATTR_DIGITAL,                                      No_ADC_Channel, NOT_ON_PWM, NOT_ON_TIMER, EXTERNAL_INT_NONE},
  
  //25
  { PORTB,  9, PIO_OUTPUT,      PIN_ATTR_DIGITAL,                                      No_ADC_Channel, NOT_ON_PWM, NOT_ON_TIMER, EXTERNAL_INT_NONE},
  
  //26
  { PORTB, 12, PIO_OUTPUT,      PIN_ATTR_DIGITAL,                                      No_ADC_Channel, NOT_ON_PWM, NOT_ON_TIMER, EXTERNAL_INT_NONE},
  
  //27
  { PORTB, 15, PIO_OUTPUT,      PIN_ATTR_DIGITAL,                                      No_ADC_Channel, NOT_ON_PWM, NOT_ON_TIMER, EXTERNAL_INT_NONE},
  
  //28
  { PORTB, 16, PIO_OUTPUT,      PIN_ATTR_DIGITAL,                                      No_ADC_Channel, NOT_ON_PWM, NOT_ON_TIMER, EXTERNAL_INT_NONE},
  
  //29
  { PORTB, 17, PIO_OUTPUT,      PIN_ATTR_DIGITAL,                                      No_ADC_Channel, NOT_ON_PWM, NOT_ON_TIMER, EXTERNAL_INT_NONE},
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

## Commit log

2021-02-18 added bootloader for custom development board
    [sodaq_explorer.cfg]
2021-02-18 added first board variant
2021-03-12 updated files and included kicad project
    [142-0701-801--3DModel-STEP-231308.STEP, ABS07-32.768KHZ-T--3DModel-STEP-56544.STEP, LQH5BPN100M38K.STEP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]
2021-03-12 added images of the pcb
    [LoRaWAN_SCM.kicad_pcb]
2021-04-02 updated arduino code and fixed usb isuue on pcb
    [LoRaWAN_SCM.kicad_pcb, LoRaWAN_SCM.kicad_sch]
